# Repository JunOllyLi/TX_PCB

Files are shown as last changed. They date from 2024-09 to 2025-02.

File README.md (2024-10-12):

NOTE: the latest PCB had been manufactured was v2.0. But it had the Gimbal ZH-connector reversed. The schematics and PCB drawing had been updated to v2.1 to fix that. But v2.1 had not been really manufactured yet.

By default, Muffin is designed to use FlySky hall gimblal, over UART. However, if any other gimbals can be used with two wires (4 including GND and 3.3V), SW can be modified to use that.

Two RF module interfaces were designed. Although the name of them are for INTMOD and EXTMOD, SW can totally choose how they were used. The default configuration has the ELRS module connected to INTMOD and 4in1 connected to EXTMOD.

Those two modules have their own individual 5V power supply, controled by SW.
The PPM in/out on the back of FS6 shares the same signal pins of the EXTMOD.

And again, although the default design for them are UART and PPM, SW can totally choose other two wires protocol. ESP32 is very flexible regarding pin muxing.

# BOM (parts not listed in the schematics)
+ display module: IL9488 https://www.aliexpress.us/item/3256803764394132.html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
+ CPU ESP32S3 N16R8: https://www.aliexpress.us/item/3256805164206118.html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
+ Zorro 4in1 module
+ Zorro ELRS module

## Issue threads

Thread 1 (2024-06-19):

Schematics available??

PravarHegde, 2024-06-19:
Schematic photo available??

JunOllyLi, 2024-06-20:
sorry I don't have that in hand. You can install the open source KiCAD to view the schematics

PravarHegde, 2024-06-20:
> sorry I don't have that in hand. You can install the open source KiCAD to view the schematics

Ooh it has multiple schematic

Closed 2024-06-20.

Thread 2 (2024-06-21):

Progress

JunOllyLi, 2024-06-21:
Start a thread to record progress.
Received the FS6-adapter board. The "Core board" got stuck in shipping and wouldn't be here for another couple of weeks. :(

Soldered the FS-adapter board. Electronically all can be really tested is that PC recognized the USB-serial port when plug in to the PC.

Mechanically, three issues found so far:
1. Two mounting holes were about 1mm off the pole in the FS6 case.
2. Components around the ADS1015 too close to the mounting hole for the TRIM lever.
3. Two buttons were 5mm off, maybe I mistakenly flipped it when I did the measurement.

Other than those, it fits into the FS6 case well (with the mounting hole filed a little bit) :)
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

JunOllyLi, 2024-07-14:
Soldered the core board.
Immediately found a big issue that the touch FPC 6pins were reversed. :( Fortunately I have some 6pin FPC adapters from other projects.

Device can power up, and ESP32 can be flashed and monitored over UART1 (from the USB port on the FS6 adapter board).

Next step is to port the SW while verifying HW.

JunOllyLi, 2024-07-24:
EdgeTX running, parts verified and working:
LCD, touch, RTC, charging, SD
MCP23017 ~ all the keys/switches/trims, as well as power switch and 3V3 control

JunOllyLi, 2024-07-29:
Working:
5V, audio, gimbal UART, both ADS1015, 4in1 internal module
Mechanically it works, fits into the FS6 case
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

Issues:
1. Resistors for dividing VBATT for ADC reading needs to be adjusted. Original values are not total failure but when charging the VBATT reading may exceeds 2.048V and cause this ADC channel requiring different gain than other channels, which is not a problem but not good either. Adjusted the resistors to 732K --- 1M + 100K
2. SD card slot too close to the big button on the FS6 adapter board. Actually they overlapped. Had to cut the button in half.
3. ELRS module not working yet. But the connection works when connected the 4in1 module on this port. So It is more a SW issue.
4. The "factory cable" of 4in1 has 5pins on the board, which should be identical to the ELRS connector, except the BOOT pin not connected.
5. The "factory cable" for the Gimbal is actually ZH 1.5mm instead of MX 1.25mm

JunOllyLi, 2024-08-02:
Issues:
1. PWR_EN LED (external) missed a current limit resistor
2. CHARGING_LED/CHG_DONE LED current limit resistor too big

Verified:
1. ELRS works. It starts and bind to RX and got telemetry reading. Although RX has not been connected to any FC to really control anything yet
2. The power designed for the PPM_I/PPM_O port was tested by connecting the 4in1 module to it and assign the two pins as UART instead. This actually can be a valid combination, one port with ELRS and one port with 4in1

JunOllyLi, 2024-08-06:
Ah! such a stupid math (high school physics) error on the POT voltage offset resistors, which made the measured voltage not linear to the POT position. :(

MNS26, 2024-10-13:
(Just found this repo via rcgroups through discord.)

Wow this looks epic, definitely gonna try making a pcb for the tx16s. (future me is gonna hate passed me for it)
And starring both this and the port repo!

Have you though about using the [`project` tab](https://github.com/JunOllyLi/TX_PCB/projects) for keeping track of what needs to be done? (Possibly also for esp ETX port?)

JunOllyLi, 2024-10-14:
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

Ah, good to know. I am not really an expert of GitHub and did not know those features. I probably should have used that.

And good luck on your PCB. You will like it 😄

MNS26, 2024-10-15:
It's never too late to learn stuff 😉.
I've used the projects only on my latest project tough... And even then omly as a todo list. You _can_ connect it to issues too but i didn't bother.

Its gonna be a real big challenge to make PCB, especially with how many pin go to the display, switches, analog and more. But I've have made PCBs before so that's a start.

On a different note... Have you thought of slightly overclocking the esp? In the videos from rcgroups it looks a bit choppy with tne UI.

JunOllyLi, 2024-10-15:
No I have not thought about over clock the ESP32. I personally feel the UI is smooth enough for me. And besides, with a different display panel as well as maybe better connection with the PCB instead of the flying wires in the old video, I was able to double the clock frequency on the display bus.

I do not have the device in hand right now. If you want, let me know which user scenario you want to see and I can capture a new video later during the weekend :)

my187119, 2024-12-23:
EN and BOOT0 No pull-up resistor connected to V3

my187119, 2024-12-23:
If only ESP32-S3, ICD and SD card are used, can the display be displayed normally?

JunOllyLi, 2024-12-24:
> If only ESP32-S3, ICD and SD card are used, can the display be displayed normally?

I think so.

JunOllyLi, 2024-12-24:
> EN and BOOT0 No pull-up resistor connected to V3

If I remember correctly those pins have weak pullup internally.

my187119, 2024-12-26:
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
I tried it, but it doesn't seem to display properly. I don't know what went wrong. Can you share the firmware you burned? My email address is my1871192876@gmail.com

JunOllyLi, 2024-12-26:
> ![20241226213828](https://private-user-images.githubusercontent.com/41514597/398738902-41250087-f3c9-45d8-a87b-dcd64e594e50.jpg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) I tried it, but it doesn't seem to display properly. I don't know what went wrong. Can you share the firmware you burned? My email address is [my1871192876@gmail.com](mailto:my1871192876@gmail.com)

1. I have never paid attention to which file is the firmware I burned. I always just do build/flash/monitor inside the ESP toolchain. If you know which file you need to flash I can send you that file.
2. You should be able to see some debug message out of the USB port (as USB-serial device). I think my default configuration builds the image that way. But from the picture it seems you were using an external USB-serial adapter? then you do need to change the configuration to output debug message to UART

my187119, 2024-12-27:
<root_of_src>/radio/src/targets/muffin/esp32_build/build, can you zip and send me this build folder?

JunOllyLi, 2024-12-27:
I think this would too big to send over email
107086546 Dec 26 19:29 muffin.tgz

my187119, 2024-12-27:
You can use Google Drive or other cloud and give me a link.

JunOllyLi, 2024-12-27:
alright, here you go: https://1drv.ms/u/s!AiiSOhBhXEkvh6B4GDPaxqTEsL-ymg?e=PmLsxo

my187119, 2024-12-27:
OK! Thanks bro!

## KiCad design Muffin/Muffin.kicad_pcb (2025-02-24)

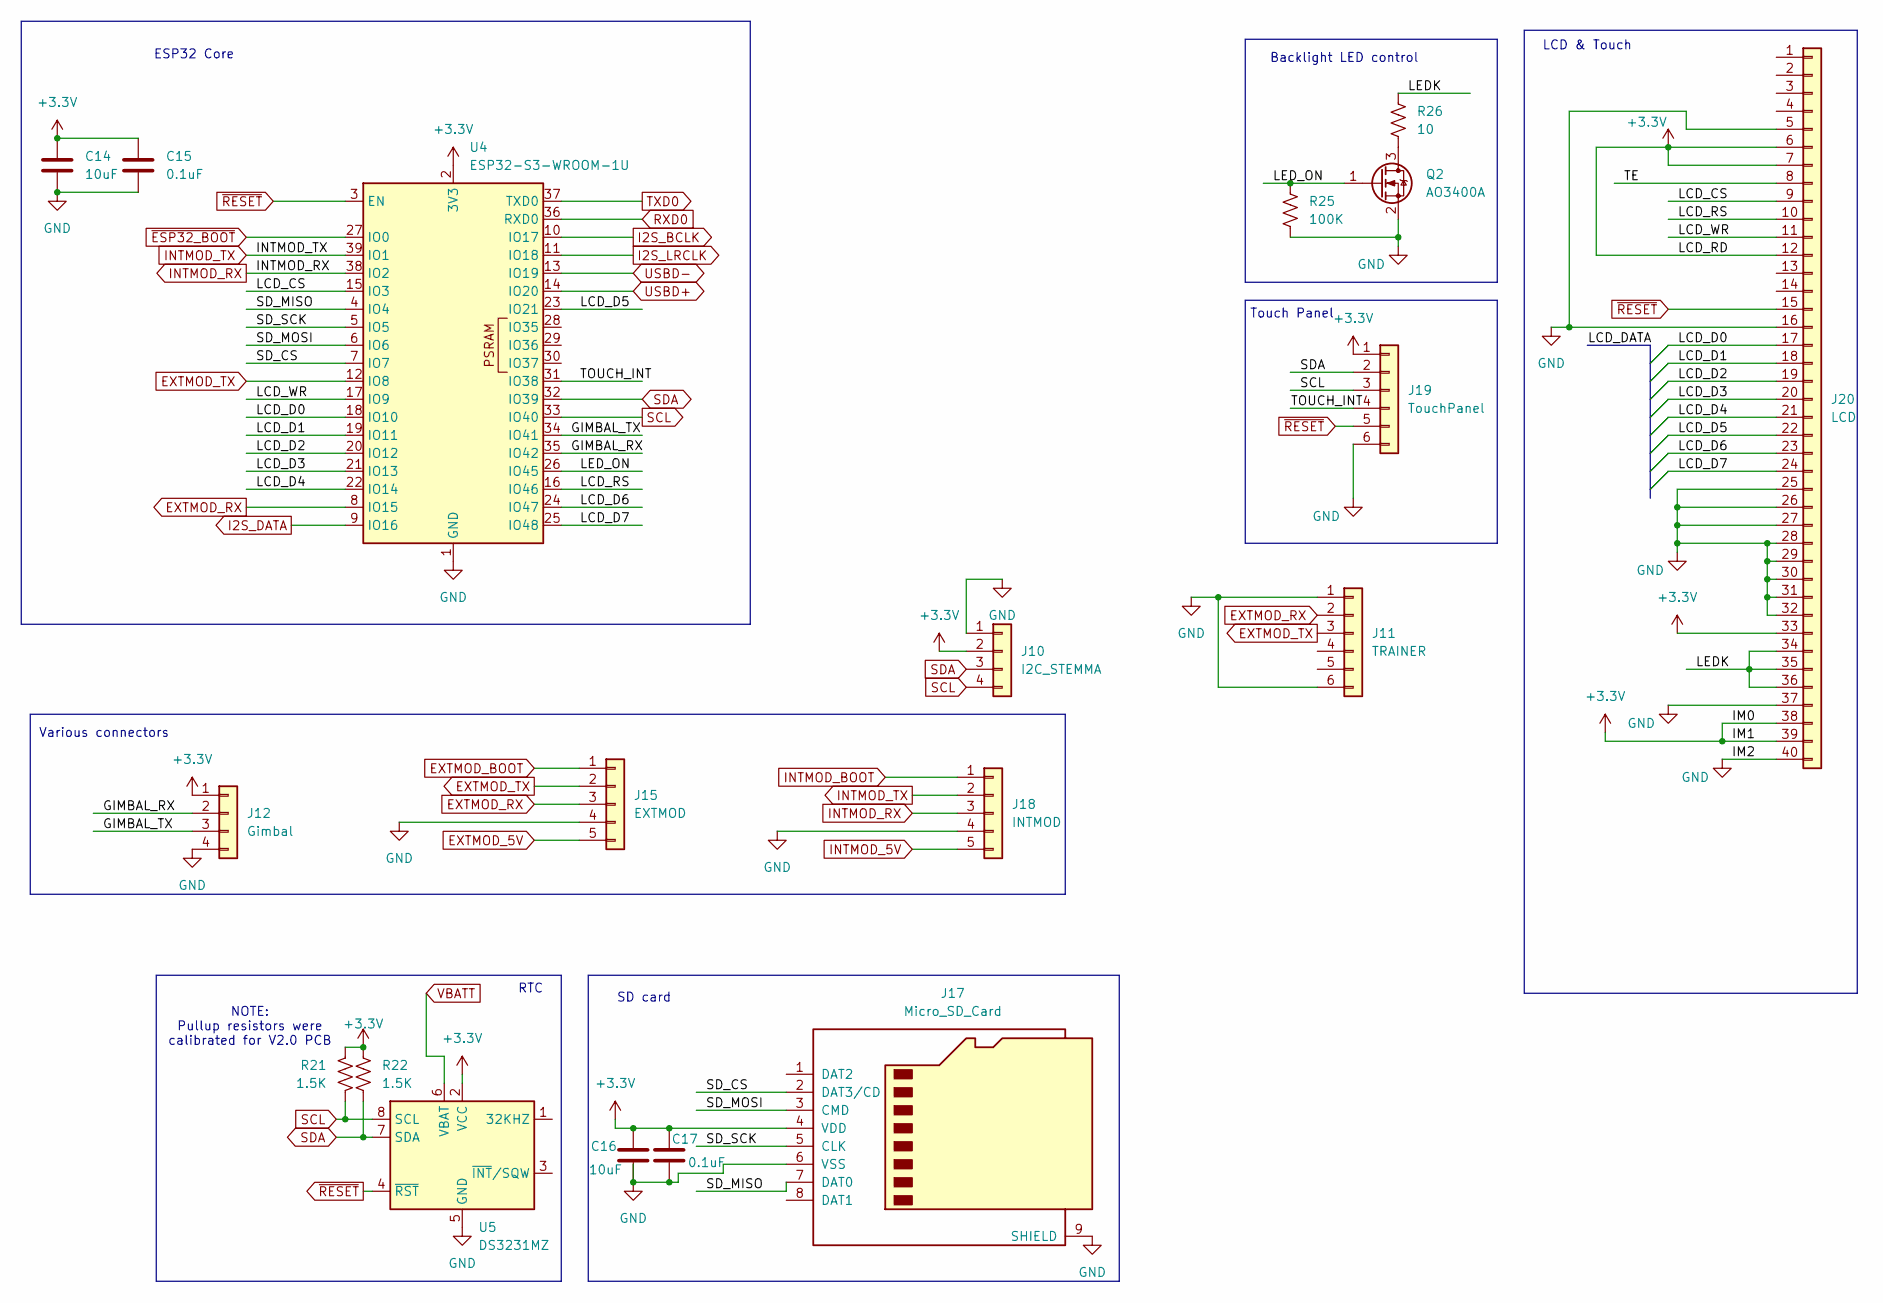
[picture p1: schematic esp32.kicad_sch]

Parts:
C14, C16: 10uF; C_0603_1608Metric
C15, C17: 0.1uF; C_0603_1608Metric
J10: I2C_STEMMA; JST_SH_BM04B-SRSS-TB_1x04-1MP_P1.00mm_Vertical
J11: TRAINER; JST_ZH1.50mm_6_PIN_Vertical
J12: Gimbal; JST_ZH_B4B-ZR-SM4-TF_1x04-1MP_P1.50mm_Vertical
J15: EXTMOD; Molex_PicoBlade_53398-0571_1x05-1MP_P1.25mm_Vertical
J17: Micro_SD_Card; MicroSD
J18: INTMOD; Molex_PicoBlade_53398-0571_1x05-1MP_P1.25mm_Vertical
J19: TouchPanel; FPC_6PIN_BOTTOM
J20: LCD; FPC_40PIN_TOP
Q2: AO3400A; SOT-23
R21, R22: 1.5K; R_0603_1608Metric
R25: 100K; R_0603_1608Metric
R26: 10; R_0603_1608Metric
U4: ESP32-S3-WROOM-1U
U5: DS3231MZ; SOIC-8_3.9x4.9mm_P1.27mm

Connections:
+3.3V: C14.1, C15.1, C16.1, C17.1, J10.2, J12.1, J17.4 (VDD), J19.1, J20.6, J20.7, J20.12, J20.33, J20.38, J20.39, R21.1, R22.1, U4.2 (3V3), U5.2 (VCC); also elsewhere on the board
/ESP32 Core/GIMBAL_RX: J12.2, U4.35 (IO42)
/ESP32 Core/GIMBAL_TX: J12.3, U4.34 (IO41)
/ESP32 Core/LCD_CS: J20.9, U4.15 (IO3)
/ESP32 Core/LCD_D0: J20.17, U4.18 (IO10)
/ESP32 Core/LCD_D1: J20.18, U4.19 (IO11)
/ESP32 Core/LCD_D2: J20.19, U4.20 (IO12)
/ESP32 Core/LCD_D3: J20.20, U4.21 (IO13)
/ESP32 Core/LCD_D4: J20.21, U4.22 (IO14)
/ESP32 Core/LCD_D5: J20.22, U4.23 (IO21)
/ESP32 Core/LCD_D6: J20.23, U4.24 (IO47)
/ESP32 Core/LCD_D7: J20.24, U4.25 (IO48)
/ESP32 Core/LCD_RS: J20.10, U4.16 (IO46)
/ESP32 Core/LCD_WR: J20.11, U4.17 (IO9)
/ESP32 Core/LEDK: J20.34, J20.35, J20.36, R26.1
/ESP32 Core/LED_ON: Q2.1 (G), R25.1, U4.26 (IO45)
/ESP32 Core/SD_CS: J17.2 (DAT3/CD), U4.7 (IO7)
/ESP32 Core/SD_MISO: J17.7 (DAT0), U4.4 (IO4)
/ESP32 Core/SD_MOSI: J17.3 (CMD), U4.6 (IO6)
/ESP32 Core/SD_SCK: J17.5 (CLK), U4.5 (IO5)
/ESP32 Core/TE: J20.8
/ESP32 Core/TOUCH_INT: J19.4, U4.31 (IO38)
EXTMOD_5V: J15.5; also elsewhere on the board
EXTMOD_BOOT: J15.1; also elsewhere on the board
EXTMOD_RX: J11.2, J15.3, U4.8 (IO15)
EXTMOD_TX: J11.3, J15.2, U4.12 (IO8)
GND: C14.2, C15.2, C16.2, C17.2, J10.1, J11.1, J11.6, J12.4, J15.4, J17.6 (VSS), J17.9 (SHIELD), J18.4, J19.6, J20.5, J20.16, J20.25, J20.26, J20.27, J20.28, J20.29, J20.30, J20.31, J20.32, J20.37, J20.40, Q2.2 (S), R25.2, U4.1 (GND), U4.40 (GND), U4.41 (GND), U5.5 (GND); also elsewhere on the board
I2S_BCLK: U4.10 (IO17); also elsewhere on the board
I2S_DATA: U4.9 (IO16); also elsewhere on the board
I2S_LRCLK: U4.11 (IO18); also elsewhere on the board
INTMOD_5V: J18.5; also elsewhere on the board
INTMOD_BOOT: J18.1; also elsewhere on the board
INTMOD_RX: J18.3, U4.38 (IO2)
INTMOD_TX: J18.2, U4.39 (IO1)
unnamed: Q2.3 (D), R26.2
RXD0: U4.36 (RXD0); also elsewhere on the board
SCL: J10.4, J19.3, R21.2, U4.33 (IO40), U5.8 (SCL); also elsewhere on the board
SDA: J10.3, J19.2, R22.2, U4.32 (IO39), U5.7 (SDA); also elsewhere on the board
TXD0: U4.37 (TXD0); also elsewhere on the board
USBD+: U4.14 (IO20); also elsewhere on the board
USBD-: U4.13 (IO19); also elsewhere on the board
VBATT: U5.6 (VBAT); also elsewhere on the board
~ESP32_BOOT: U4.27 (IO0); also elsewhere on the board
~RESET: J19.5, J20.15, U4.3 (EN), U5.4 (~RST); also elsewhere on the board

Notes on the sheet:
Touch Panel
NOTE: Pullup resistors were calibrated for V2.0 PCB
ESP32 Core
Backlight LED control
Various connectors
RTC
LCD & Touch
SD card

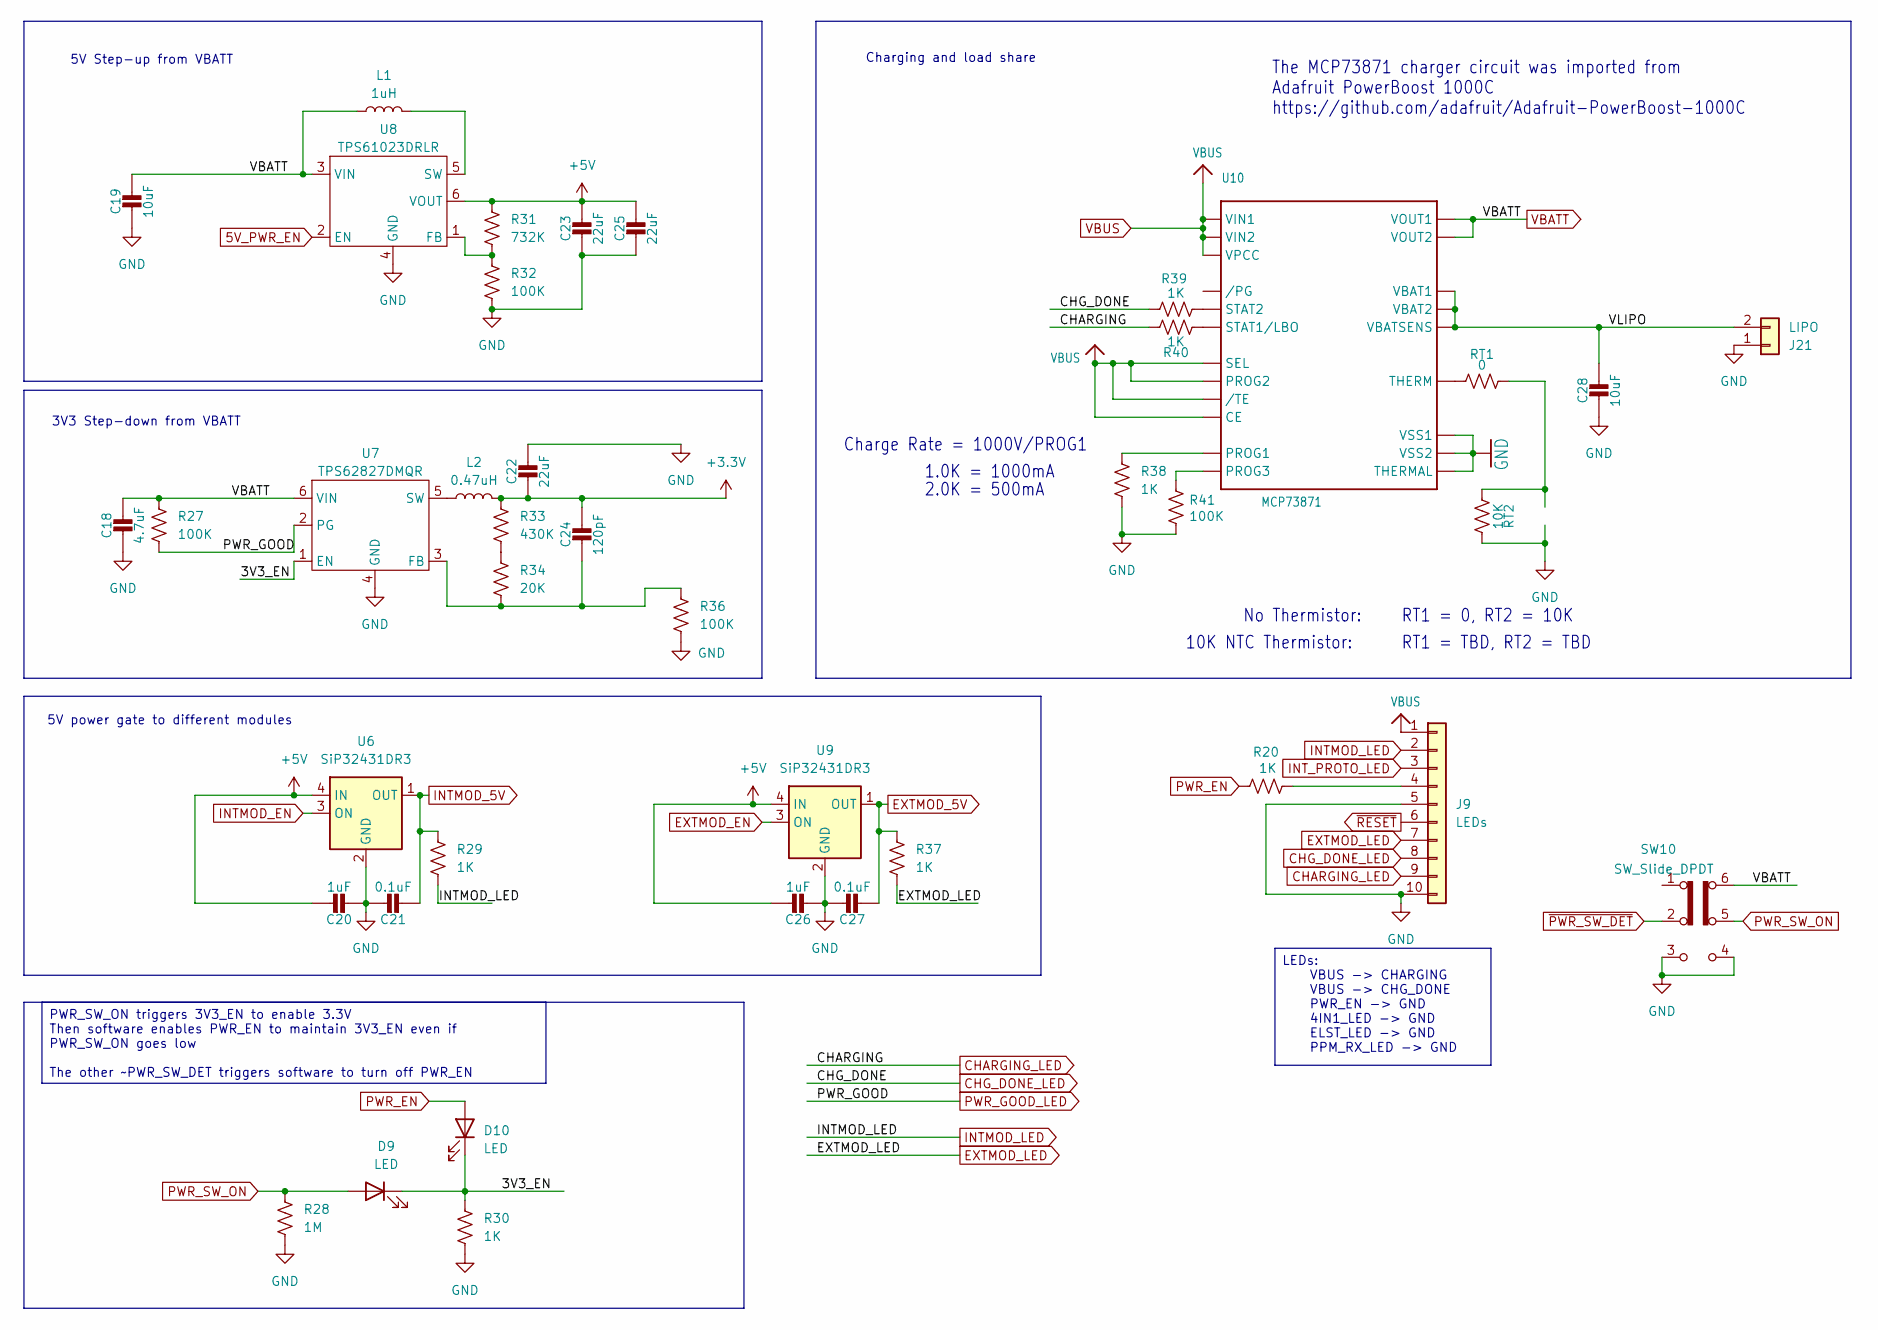
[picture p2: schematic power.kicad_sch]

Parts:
C18: 4.7uF; C_0603_1608Metric
C19, C28: 10uF; C_0603_1608Metric
C20, C26: 1uF; C_0603_1608Metric
C21, C27: 0.1uF; C_0603_1608Metric
C22, C23, C25: 22uF; C_0603_1608Metric
C24: 120pF; C_0603_1608Metric
D9, D10: LED; LED_0603_1608Metric
J9: LEDs; JST_GH_BM10B-GHS-TBT_1x10-1MP_P1.25mm_Vertical
J21: LIPO; AMASS_XT30UPB-M_1x02_P5.0mm_Vertical
L1: 1uH; L_Cenker_CKCS4020
L2: 0.47uH; L_Cenker_CKCS4020
R20, R29, R30, R37, R38, R39, R40: 1K; R_0603_1608Metric
R27, R32, R36, R41: 100K; R_0603_1608Metric
R28: 1M; R_0603_1608Metric
R31: 732K; R_0603_1608Metric
R33: 430K; R_0603_1608Metric
R34: 20K; R_0603_1608Metric
RT1: 0; R_0603_1608Metric
RT2: 10K; R_0603_1608Metric
SW10: SW_Slide_DPDT; SW_SLIDE_DPDT_7mm
U6, U9: SiP32431DR3; SOT-363_SC-70-6
U7: TPS62827DMQR; DMQ_6
U8: TPS61023DRLR; Texas_R-PDSO-N6_DRL-6
U10: MCP73871; QFN-20-1EP_4x4mm_P0.5mm_EP2.5x2.5mm

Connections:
5V_PWR_EN: U8.2 (EN); also elsewhere on the board
+3.3V: C22.2, C24.1, L2.2, R33.1; also elsewhere on the board
+5V: C20.1, C23.1, C25.1, C26.1, R31.1, U6.4 (IN), U8.6 (VOUT), U9.4 (IN); also elsewhere on the board
/Power/3V3_EN: D9.1 (K), D10.1 (K), R30.1, U7.1 (EN)
/Power/VLIPO: C28.1, J21.2, U10.14 (VBAT1), U10.15 (VBAT2), U10.16 (VBATSENS)
CHARGING_LED: J9.9, R40.1
CHG_DONE_LED: J9.8, R39.1
EXTMOD_5V: C27.2, R37.1, U9.1 (OUT); also elsewhere on the board
EXTMOD_EN: U9.3 (ON); also elsewhere on the board
EXTMOD_LED: J9.7, R37.2
GND: C18.2, C19.2, C20.2, C21.1, C22.1, C23.2, C25.2, C26.2, C27.1, C28.2, J9.5, J9.10, J21.1, R28.2, R30.2, R32.2, R36.2, R38.2, R41.2, RT2.2, SW10.3 (C), SW10.4 (A), U6.2 (GND), U6.5 (GND), U7.4 (GND), U8.4 (GND), U9.2 (GND), U9.5 (GND), U10.10 (VSS1), U10.11 (VSS2), U10.21 (THERMAL); also elsewhere on the board
INTMOD_5V: C21.2, R29.1, U6.1 (OUT); also elsewhere on the board
INTMOD_EN: U6.3 (ON); also elsewhere on the board
INTMOD_LED: J9.2, R29.2
INT_PROTO_LED: J9.3; also elsewhere on the board
unnamed: J9.4, R20.1
unnamed: R33.2, R34.1
unnamed: RT1.2, RT2.1
unnamed: C24.2, R34.2, R36.1, U7.3 (FB)
unnamed: L2.1, U7.5 (SW)
unnamed: R31.2, R32.1, U8.1 (FB)
unnamed: L1.2, U8.5 (SW)
unnamed: R38.1, U10.13 (PROG1)
unnamed: R41.1, U10.12 (PROG3)
unnamed: R40.2, U10.8 (STAT1/LBO)
unnamed: R39.2, U10.7 (STAT2)
unnamed: RT1.1, U10.5 (THERM)
PWR_EN: D10.2 (A), R20.2; also elsewhere on the board
PWR_GOOD_LED: R27.2, U7.2 (PG)
PWR_SW_ON: D9.2 (A), R28.1, SW10.5 (B)
VBATT: C18.1, C19.1, L1.1, R27.1, SW10.6 (C), U7.6 (VIN), U8.3 (VIN), U10.1 (VOUT1), U10.20 (VOUT2); also elsewhere on the board
VBUS: J9.1, U10.2 (VPCC), U10.3 (SEL), U10.4 (PROG2), U10.9 (/TE), U10.17 (CE), U10.18 (VIN1), U10.19 (VIN2); also elsewhere on the board
~PWR_SW_DET: SW10.2 (B); also elsewhere on the board
~RESET: J9.6; also elsewhere on the board

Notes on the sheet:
10K NTC Thermistor:
5V power gate to different modules
The MCP73871 charger circuit was imported from Adafruit PowerBoost 1000C https://github.com/adafruit/Adafruit-PowerBoost-1000C
5V Step-up from VBATT
1.0K = 1000mA
No Thermistor:
Charge Rate = 1000V/PROG1
RT1 = TBD, RT2 = TBD
Charging and load share
3V3 Step-down from VBATT
RT1 = 0, RT2 = 10K
2.0K = 500mA
LEDs: VBUS -> CHARGING VBUS -> CHG_DONE PWR_EN -> GND 4IN1_LED -> GND ELST_LED -> GND PPM_RX_LED -> GND
PWR_SW_ON triggers 3V3_EN to enable 3.3V Then software enables PWR_EN to maintain 3V3_EN even if PWR_SW_ON goes low The other ~PWR_SW_DET triggers software to turn off PWR_EN

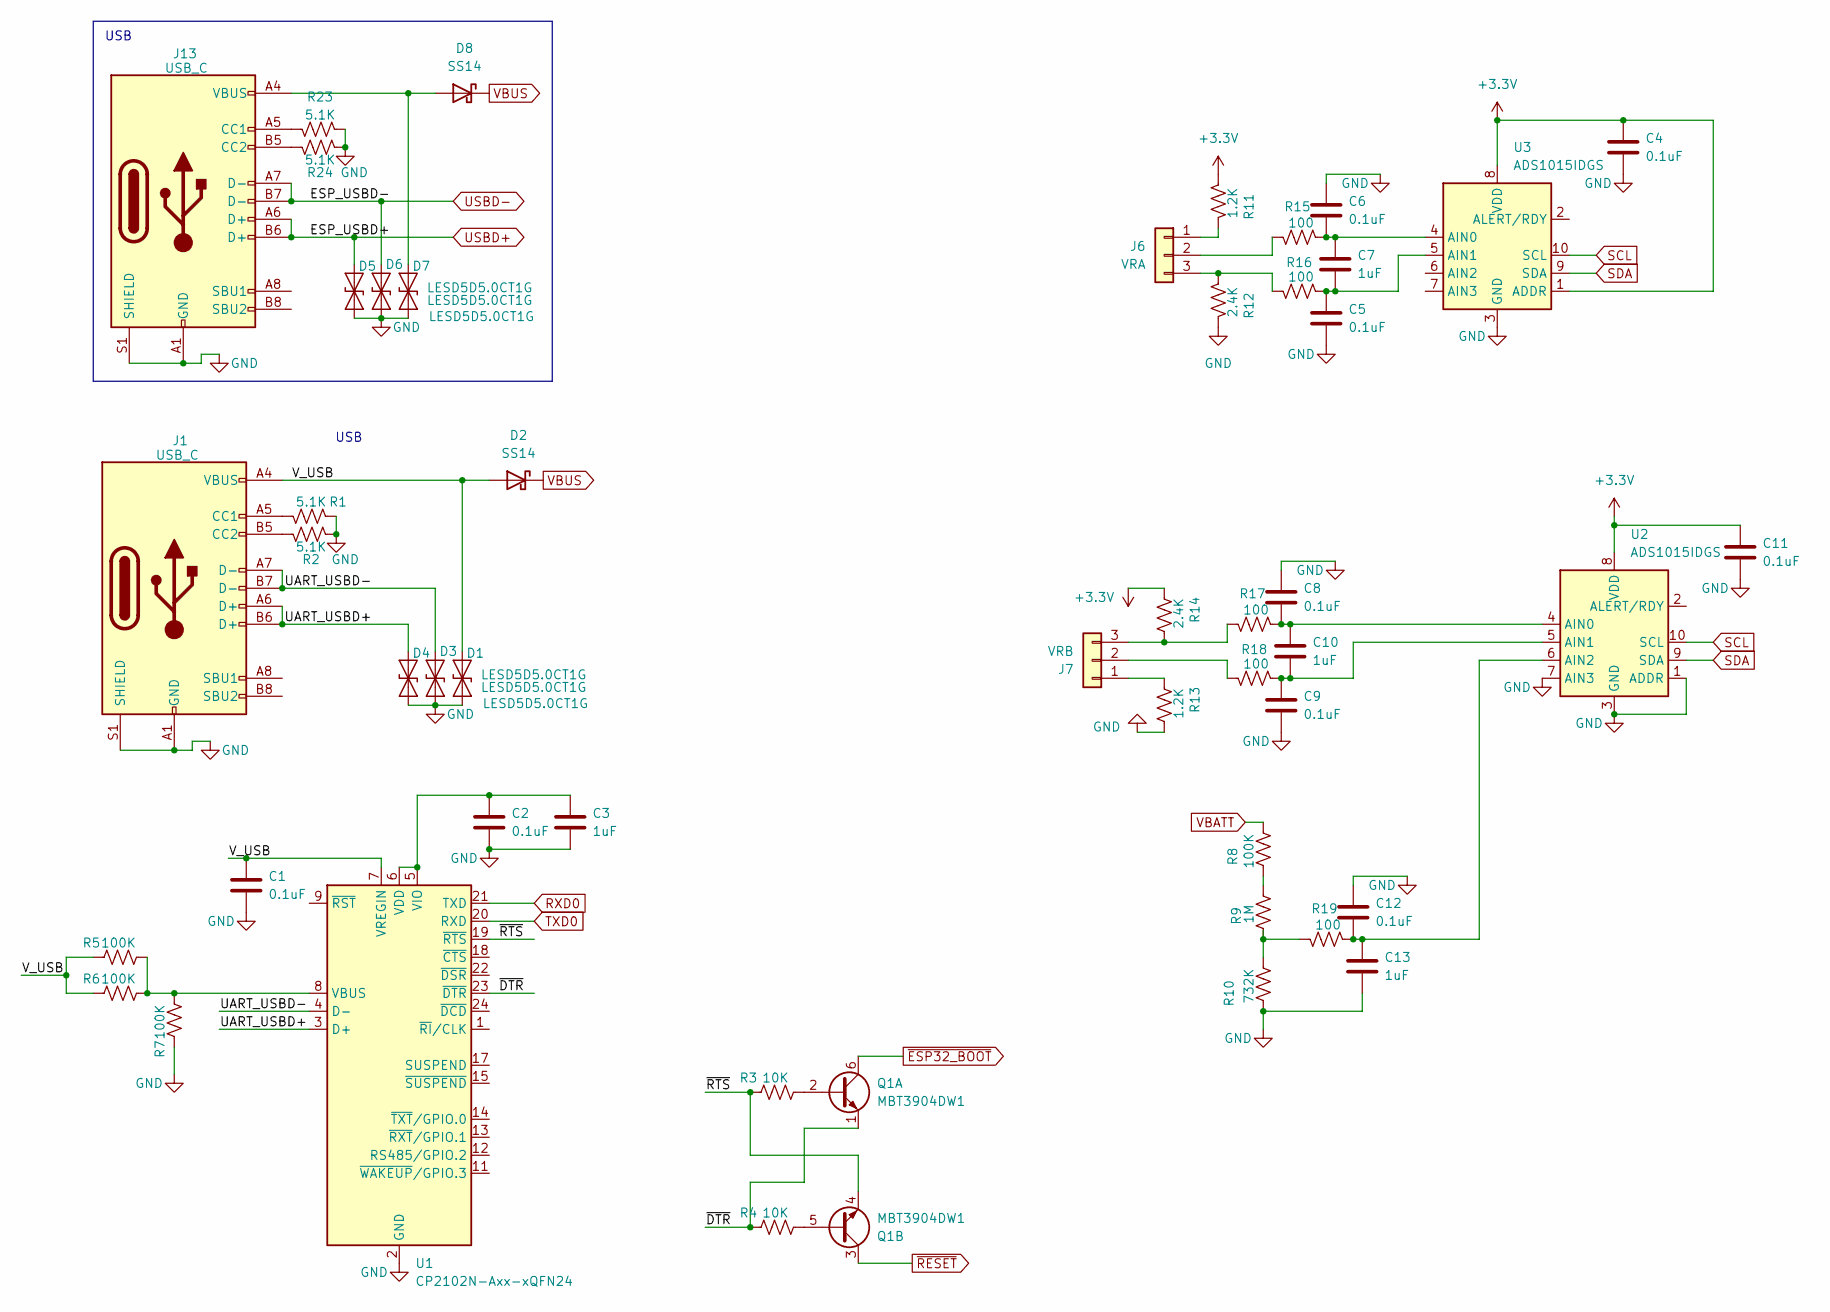
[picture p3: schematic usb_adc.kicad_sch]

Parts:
C1, C2, C4, C5, C6, C8, C9, C11, C12: 0.1uF; C_0603_1608Metric
C3, C7, C10, C13: 1uF; C_0603_1608Metric
D1, D3, D4, D5, D6, D7: LESD5D5.0CT1G; D_SOD-523
D2, D8: SS14; D_SMA
J1, J13: USB_C; my_USB_C_Receptacle_GCT_USB4105-xx-A_16P_TopMnt_Horizontal
J6: VRA; JST_GH_BM03B-GHS-TBT_1x03-1MP_P1.25mm_Vertical
J7: VRB; JST_GH_BM03B-GHS-TBT_1x03-1MP_P1.25mm_Vertical
Q1: MBT3904DW1; SOT-363_SC-70-6
R1, R2, R23, R24: 5.1K; R_0603_1608Metric
R3, R4: 10K; R_0603_1608Metric
R5, R6, R7, R8: 100K; R_0603_1608Metric
R9: 1M; R_0603_1608Metric
R10: 732K; R_0603_1608Metric
R11, R13: 1.2K; R_0603_1608Metric
R12, R14: 2.4K; R_0603_1608Metric
R15, R16, R17, R18, R19: 100; R_0603_1608Metric
U1: CP2102N-Axx-xQFN24; QFN-24-1EP_4x4mm_P0.5mm_EP2.6x2.6mm
U2, U3: ADS1015IDGS; TSSOP-10_3x3mm_P0.5mm

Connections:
+3.3V: C4.1, C11.1, R11.2, R14.1, U2.8 (VDD), U3.1 (ADDR), U3.8 (VDD); also elsewhere on the board
/USB and ADC/UART_USBD+: D4.2 (A2), J1.A6 (D+), J1.B6 (D+), U1.3 (D+)
/USB and ADC/UART_USBD-: D3.2 (A2), J1.A7 (D-), J1.B7 (D-), U1.4 (D-)
/USB and ADC/V_USB: C1.1, D1.2 (A2), D2.2 (A), J1.A4 (VBUS), J1.A9 (VBUS), J1.B4 (VBUS), J1.B9 (VBUS), R5.1, R6.1, U1.7 (VREGIN)
/USB and ADC/~DTR: Q1.1 (E1), R4.1, U1.23 (~DTR)
/USB and ADC/~RTS: Q1.4 (E2), R3.1, U1.19 (~RTS)
GND: C1.2, C2.2, C3.2, C4.2, C5.2, C6.1, C8.1, C9.2, C11.2, C12.1, C13.2, D1.1 (A1), D3.1 (A1), D4.1 (A1), D5.1 (A1), D6.1 (A1), D7.1 (A1), J1.A1 (GND), J1.A12 (GND), J1.B1 (GND), J1.B12 (GND), J1.S1 (SHIELD), J13.A1 (GND), J13.A12 (GND), J13.B1 (GND), J13.B12 (GND), J13.S1 (SHIELD), R1.1, R2.1, R7.1, R10.1, R12.1, R13.2, R23.1, R24.1, U1.2 (GND), U1.25 (GND), U2.1 (ADDR), U2.3 (GND), U2.7 (AIN3), U3.3 (GND); also elsewhere on the board
unnamed: D7.2 (A2), D8.2 (A), J13.A4 (VBUS), J13.A9 (VBUS), J13.B4 (VBUS), J13.B9 (VBUS)
unnamed: J1.A5 (CC1), R1.2
unnamed: J1.B5 (CC2), R2.2
unnamed: J6.1, R11.1
unnamed: J6.2, R15.2
unnamed: J6.3, R12.2, R16.2
unnamed: J7.1, R13.1
unnamed: J7.2, R18.2
unnamed: J7.3, R14.2, R17.2
unnamed: J13.A5 (CC1), R23.2
unnamed: J13.B5 (CC2), R24.2
unnamed: Q1.2 (B1), R3.2
unnamed: Q1.5 (B2), R4.2
unnamed: R8.1, R9.2
unnamed: R9.1, R10.2, R19.2
unnamed: R5.2, R6.2, R7.2, U1.8 (VBUS)
unnamed: C2.1, C3.1, U1.5 (VIO), U1.6 (VDD)
unnamed: C8.2, C10.1, R17.1, U2.4 (AIN0)
unnamed: C9.1, C10.2, R18.1, U2.5 (AIN1)
unnamed: C12.2, C13.1, R19.1, U2.6 (AIN2)
unnamed: C6.2, C7.1, R15.1, U3.4 (AIN0)
unnamed: C5.1, C7.2, R16.1, U3.5 (AIN1)
RXD0: U1.21 (TXD); also elsewhere on the board
SCL: U2.10 (SCL), U3.10 (SCL); also elsewhere on the board
SDA: U2.9 (SDA), U3.9 (SDA); also elsewhere on the board
TXD0: U1.20 (RXD); also elsewhere on the board
USBD+: D5.2 (A2), J13.A6 (D+), J13.B6 (D+); also elsewhere on the board
USBD-: D6.2 (A2), J13.A7 (D-), J13.B7 (D-); also elsewhere on the board
VBATT: R8.2; also elsewhere on the board
VBUS: D2.1 (K), D8.1 (K); also elsewhere on the board
~ESP32_BOOT: Q1.6 (C1); also elsewhere on the board
~RESET: Q1.3 (C2); also elsewhere on the board

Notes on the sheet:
USB

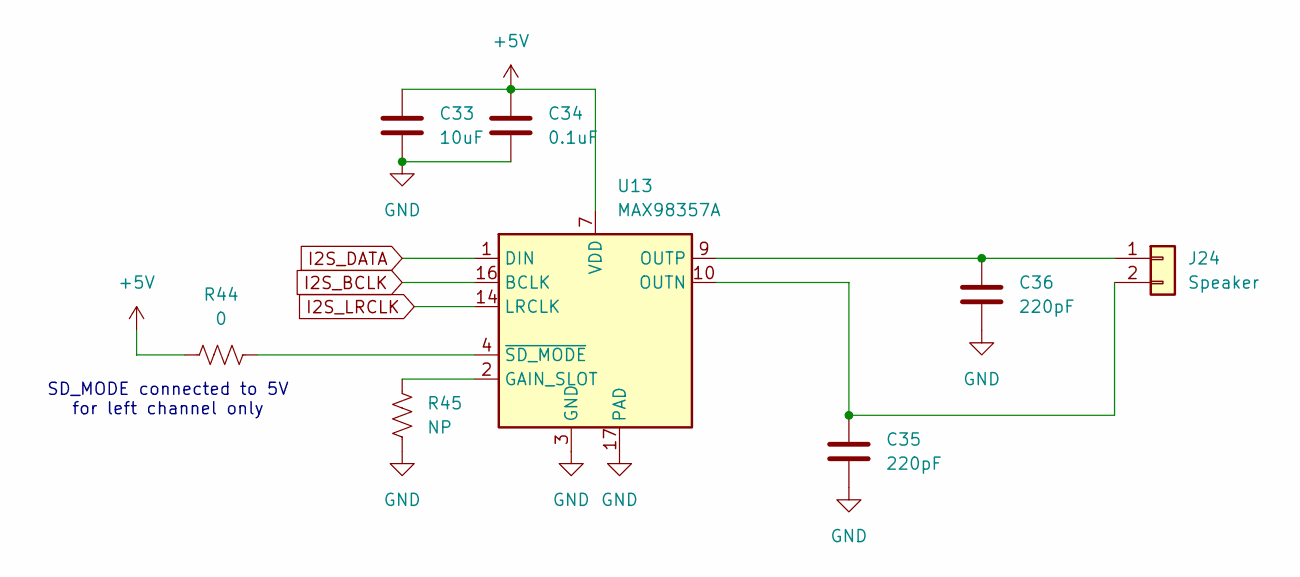
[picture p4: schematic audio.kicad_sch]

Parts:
C33: 10uF; C_0603_1608Metric
C34: 0.1uF; C_0603_1608Metric
C35, C36: 220pF; C_0603_1608Metric
J24: Speaker; Molex_PicoBlade_53398-0271_1x02-1MP_P1.25mm_Vertical
R44: 0; R_0603_1608Metric
R45: NP; R_0603_1608Metric
U13: MAX98357A; TQFN-16-1EP_3x3mm_P0.5mm_EP1.23x1.23mm

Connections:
+5V: C33.1, C34.1, R44.1, U13.7 (VDD), U13.8 (VDD); also elsewhere on the board
GND: C33.2, C34.2, C35.2, C36.2, R45.1, U13.3 (GND), U13.11 (GND), U13.15 (GND), U13.17 (PAD); also elsewhere on the board
I2S_BCLK: U13.16 (BCLK); also elsewhere on the board
I2S_DATA: U13.1 (DIN); also elsewhere on the board
I2S_LRCLK: U13.14 (LRCLK); also elsewhere on the board
unnamed: C36.1, J24.1, U13.9 (OUTP)
unnamed: C35.1, J24.2, U13.10 (OUTN)
unnamed: R45.2, U13.2 (GAIN_SLOT)
unnamed: R44.2, U13.4 (~SD_MODE)

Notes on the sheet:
SD_MODE connected to 5V for left channel only

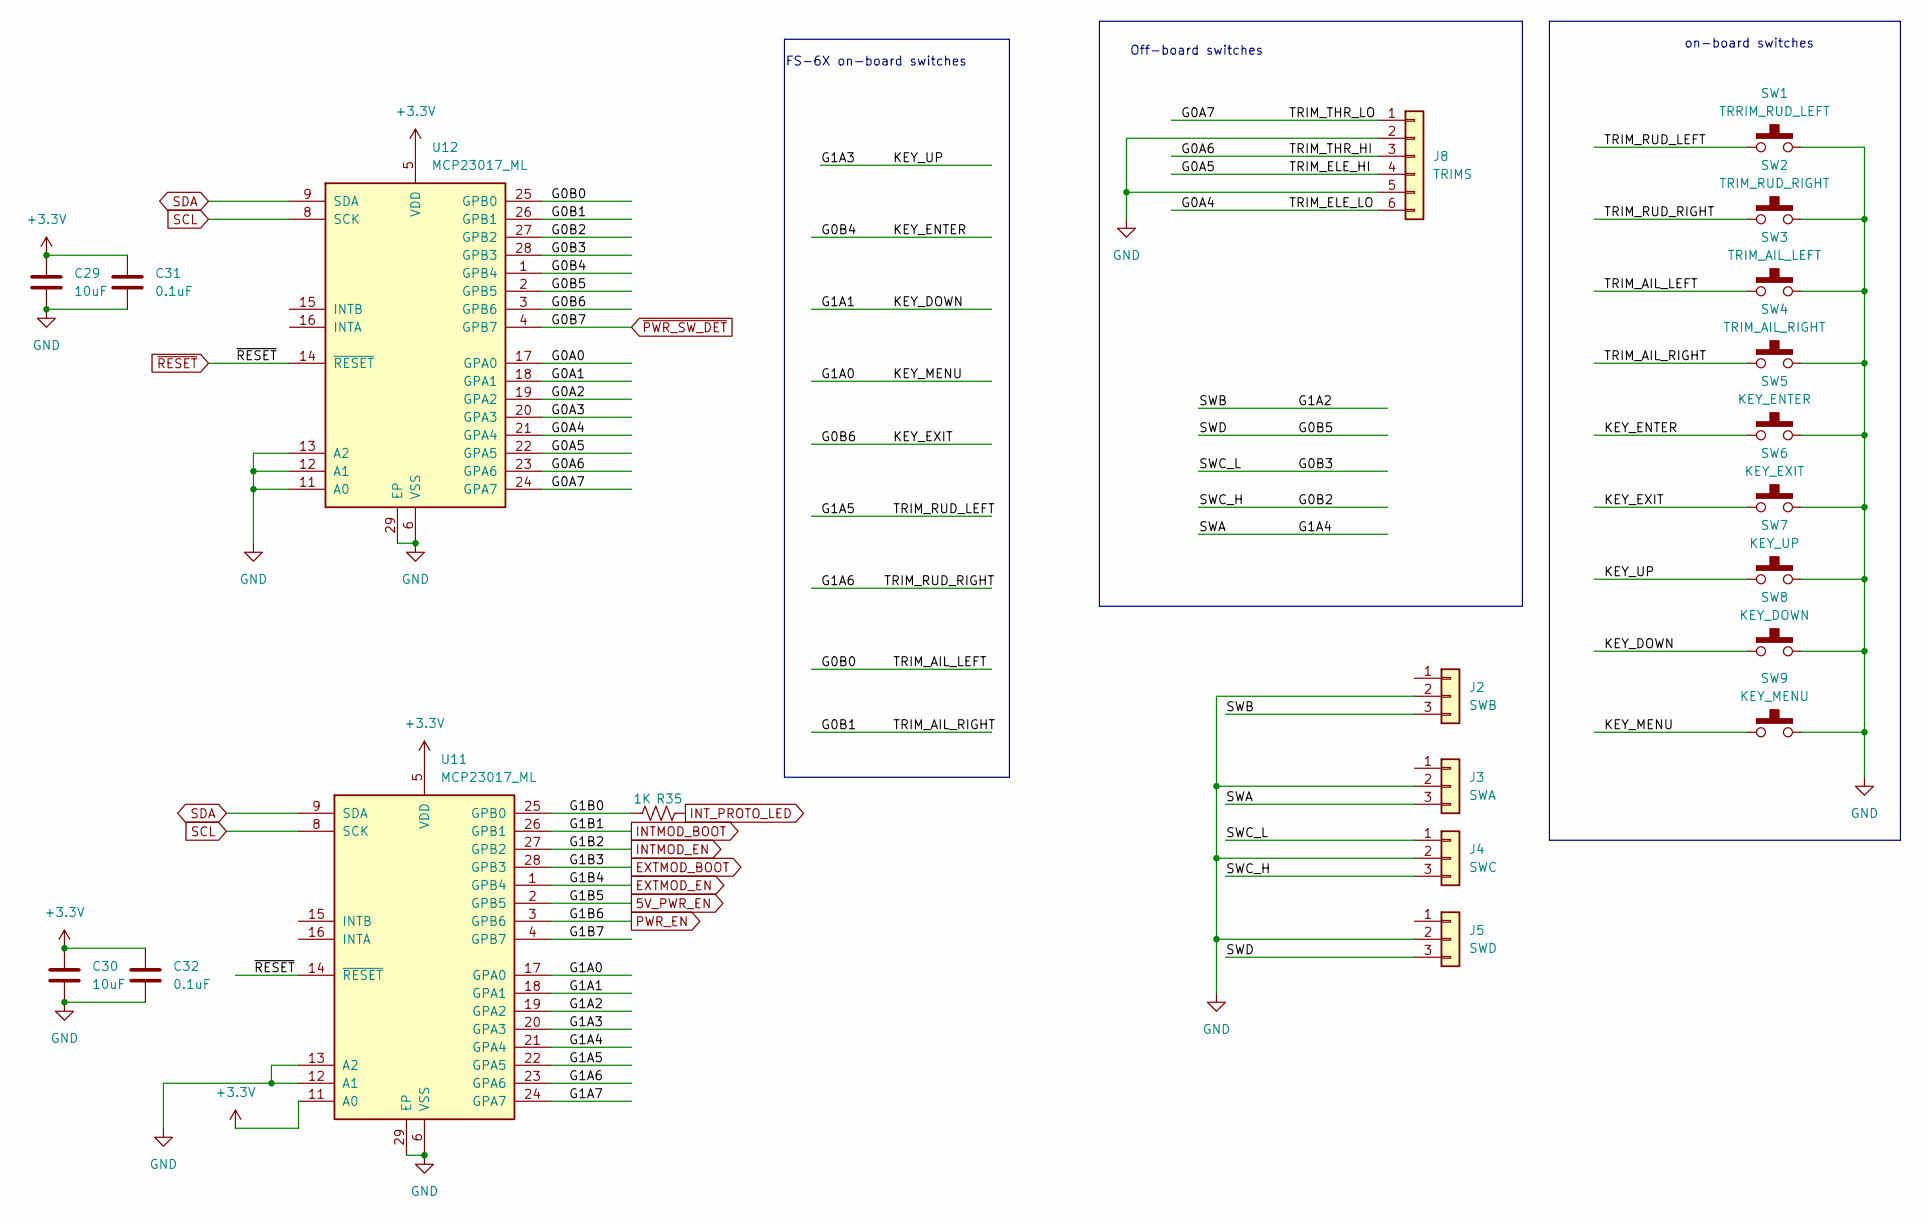
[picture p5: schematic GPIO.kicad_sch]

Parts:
C29, C30: 10uF; C_0603_1608Metric
C31, C32: 0.1uF; C_0603_1608Metric
J2: SWB; JST_GH_BM03B-GHS-TBT_1x03-1MP_P1.25mm_Vertical
J3: SWA; JST_GH_BM03B-GHS-TBT_1x03-1MP_P1.25mm_Vertical
J4: SWC; JST_GH_BM03B-GHS-TBT_1x03-1MP_P1.25mm_Vertical
J5: SWD; JST_GH_BM03B-GHS-TBT_1x03-1MP_P1.25mm_Vertical
J8: TRIMS; JST_ZH1.50mm_6_PIN_Vertical
R35: 1K; R_0603_1608Metric
SW1: TRRIM_RUD_LEFT; SW_6.2mm
SW2: TRIM_RUD_RIGHT; SW_6.2mm
SW3: TRIM_AIL_LEFT; SW_6.2mm
SW4: TRIM_AIL_RIGHT; SW_6.2mm
SW5: KEY_ENTER; SW_6.2mm
SW6: KEY_EXIT; SW_6.2mm
SW7: KEY_UP; SW_6.2mm
SW8: KEY_DOWN; SW_6.2mm
SW9: KEY_MENU; SW_12mm
U11, U12: MCP23017_ML; QFN-28-1EP_6x6mm_P0.65mm_EP4.25x4.25mm

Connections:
5V_PWR_EN: U11.2 (GPB5); also elsewhere on the board
+3.3V: C29.1, C30.1, C31.1, C32.1, U11.5 (VDD), U11.11 (A0), U12.5 (VDD); also elsewhere on the board
/GPIO_ext/G0A0: U12.17 (GPA0)
/GPIO_ext/G0A1: U12.18 (GPA1)
/GPIO_ext/G0A2: U12.19 (GPA2)
/GPIO_ext/G0A3: U12.20 (GPA3)
/GPIO_ext/G0A4: J8.6, U12.21 (GPA4)
/GPIO_ext/G0A5: J8.4, U12.22 (GPA5)
/GPIO_ext/G0A6: J8.3, U12.23 (GPA6)
/GPIO_ext/G0A7: J8.1, U12.24 (GPA7)
/GPIO_ext/G0B0: SW3.1 (A), SW3.2 (B), U12.25 (GPB0)
/GPIO_ext/G0B1: SW4.1 (A), SW4.2 (B), U12.26 (GPB1)
/GPIO_ext/G0B2: J4.3, U12.27 (GPB2)
/GPIO_ext/G0B3: J4.1, U12.28 (GPB3)
/GPIO_ext/G0B4: SW5.1 (A), SW5.2 (B), U12.1 (GPB4)
/GPIO_ext/G0B5: J5.3, U12.2 (GPB5)
/GPIO_ext/G0B6: SW6.1 (A), SW6.2 (B), U12.3 (GPB6)
/GPIO_ext/G1A0: SW9.1 (A), SW9.2 (B), U11.17 (GPA0)
/GPIO_ext/G1A1: SW8.1 (A), SW8.2 (B), U11.18 (GPA1)
/GPIO_ext/G1A2: J2.3, U11.19 (GPA2)
/GPIO_ext/G1A3: SW7.1 (A), SW7.2 (B), U11.20 (GPA3)
/GPIO_ext/G1A4: J3.3, U11.21 (GPA4)
/GPIO_ext/G1A5: SW1.1 (A), SW1.2 (B), U11.22 (GPA5)
/GPIO_ext/G1A6: SW2.1 (A), SW2.2 (B), U11.23 (GPA6)
/GPIO_ext/G1A7: U11.24 (GPA7)
/GPIO_ext/G1B0: R35.1, U11.25 (GPB0)
/GPIO_ext/G1B7: U11.4 (GPB7)
EXTMOD_BOOT: U11.28 (GPB3); also elsewhere on the board
EXTMOD_EN: U11.1 (GPB4); also elsewhere on the board
GND: C29.2, C30.2, C31.2, C32.2, J2.2, J3.2, J4.2, J5.2, J8.2, J8.5, SW1.3 (C), SW1.4 (D), SW2.3 (C), SW2.4 (D), SW3.3 (C), SW3.4 (D), SW4.3 (C), SW4.4 (D), SW5.3 (C), SW5.4 (D), SW6.3 (C), SW6.4 (D), SW7.3 (C), SW7.4 (D), SW8.3 (C), SW8.4 (D), SW9.3 (C), SW9.4 (D), U11.6 (VSS), U11.12 (A1), U11.13 (A2), U11.29 (EP), U12.6 (VSS), U12.11 (A0), U12.12 (A1), U12.13 (A2), U12.29 (EP); also elsewhere on the board
INTMOD_BOOT: U11.26 (GPB1); also elsewhere on the board
INTMOD_EN: U11.27 (GPB2); also elsewhere on the board
INT_PROTO_LED: R35.2; also elsewhere on the board
PWR_EN: U11.3 (GPB6); also elsewhere on the board
SCL: U11.8 (SCK), U12.8 (SCK); also elsewhere on the board
SDA: U11.9 (SDA), U12.9 (SDA); also elsewhere on the board
~PWR_SW_DET: U12.4 (GPB7); also elsewhere on the board
~RESET: U11.14 (~RESET), U12.14 (~RESET); also elsewhere on the board

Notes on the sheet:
Off-board switches
on-board switches
FS-6X on-board switches

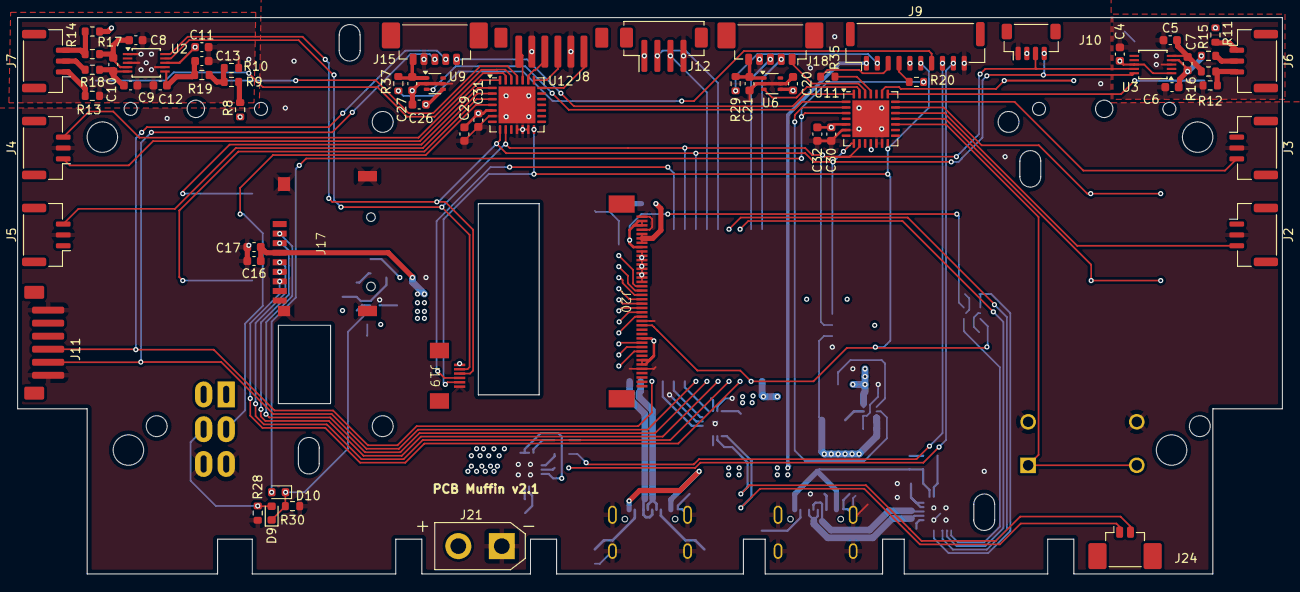
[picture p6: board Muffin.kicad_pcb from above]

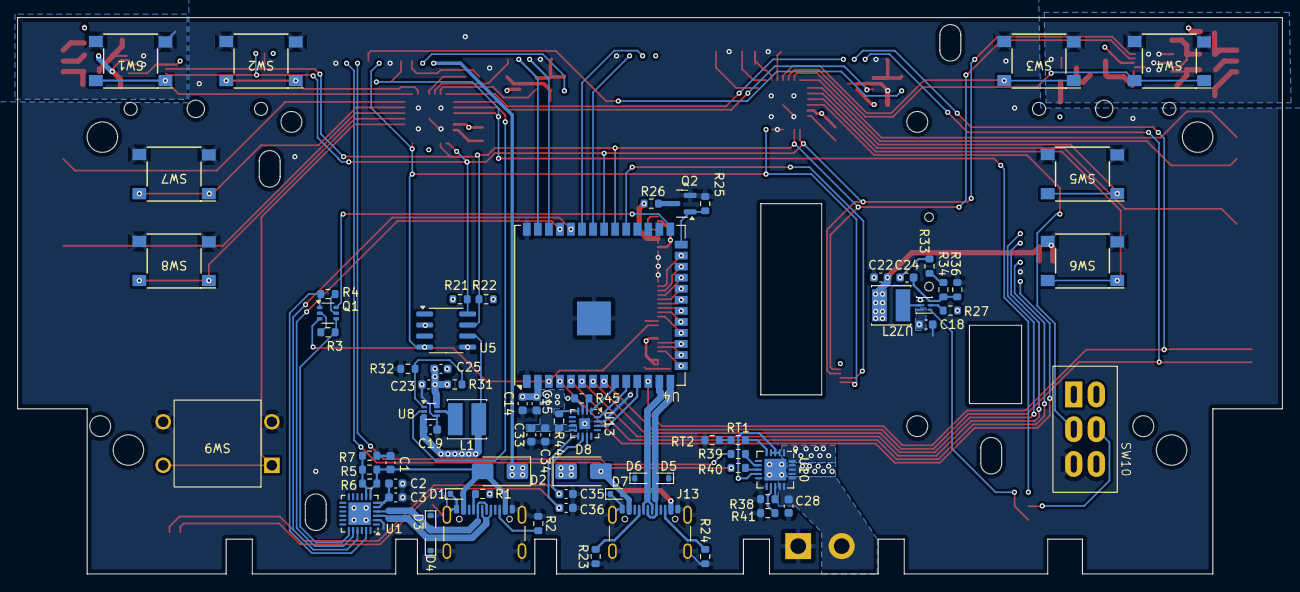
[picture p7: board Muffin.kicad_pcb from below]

Board: 4 copper layers, 145.5 x 64.0 mm, 138 parts (74 on the bottom side), 121 nets.

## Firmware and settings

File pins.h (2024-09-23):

/*
From Kconfig
  LCD D0 - D7: 10, 11, 12, 13, 14, 21, 47, 48
  LCD CS 3
  LCD DC 46
  LCD WR 9

#define I2C_SCL 7
#define I2C_SDA 6

//  MOSI -1
//  MISO -1
//  RESET -1
//  SCLK -1
//  TOUCH CS -1
//  TOUCH IRQ 38
*/

#define TOUCH_IRQ GPIO_NUM_38

#define I2C_MASTER_NUM I2C_NUM_0
#define I2C_0_SCL GPIO_NUM_40
#define I2C_0_SDA GPIO_NUM_39

#define BACKLITE_PIN GPIO_NUM_45

#define USE_RMT -1
#if CONFIG_ESP_CONSOLE_UART_NUM == 0
#define FLYSKY_UART_PORT USE_RMT
#define EXTMOD_UART_PORT UART_NUM_1
#define INTMOD_UART_PORT UART_NUM_2
#else
#define FLYSKY_UART_PORT UART_NUM_0
#define EXTMOD_UART_PORT UART_NUM_1
#define INTMOD_UART_PORT UART_NUM_2
#endif

#define FLYSKY_UART_RX_PIN GPIO_NUM_41  // GIMBLE_TX
#define FLYSKY_UART_TX_PIN GPIO_NUM_42  // GIMBLE_RX

#define INTMOD_ESP_UART_TX GPIO_NUM_2 // INTMOD_RX
#define INTMOD_ESP_UART_RX GPIO_NUM_1 // INTMOD_TX

#define EXTMOD_UART_TX GPIO_NUM_15  // EXTMOD_RX
#define EXTMOD_UART_RX GPIO_NUM_8   // EXTMOD_TX

#define SD_DEDICATED_SPI
#ifdef SD_DEDICATED_SPI
#define SD_SPI_HOST SPI2_HOST
#define SDSPI_CLK GPIO_NUM_5
#define SDSPI_MOSI GPIO_NUM_6
#define SDSPI_MISO GPIO_NUM_4
#endif
#define SDCARD_CS_GPIO GPIO_NUM_7

#define I2S_DOUT GPIO_NUM_16
#define I2S_BCLK GPIO_NUM_17
#define I2S_LRCLK GPIO_NUM_18

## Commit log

2024-05-15 Muffin PCB v1.0
    [FS6-Adapter.kicad_pcb, FS6-Adapter.kicad_sch, GPIO.kicad_sch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]
2024-08-26 Fix issues found
    [FS6-Adapter.kicad_pcb, FS6-Adapter.kicad_sch, GPIO.kicad_sch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]
2024-09-23 V2.0: Combined single board
    [FS6-Adapter.kicad_pcb, FS6-Adapter.kicad_sch, GPIO.kicad_sch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]
2024-10-12 PCB 2.1
    Fixed a reversed ZH-socket on the board for Gimbal
    [Muffin-B_Cu.gbr, Muffin-B_Mask.gbr, Muffin-B_Paste.gbr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]
2025-02-24 KiCAD 9.0
    [GPIO.kicad_sch, Muffin.kicad_pcb, Muffin.kicad_sch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]
